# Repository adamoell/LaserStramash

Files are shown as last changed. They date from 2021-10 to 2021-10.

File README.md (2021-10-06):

# LaserStramash
Weapons-grade Free Software laser tag system.

Laser Stramash is a free/open Laser Tag system. It is designed with the following values in mind:
* Free: The software and hardware designs are all free to copy, use, modify and reuse. 
* Low cost: The system is designed to be inexpensive to implement and operate.
* Exciting: Laser Stramash should be fun to play, intense and varied.
* Accessible: Laser Stramash should be implementable by hobbyists with moderate software, 3D printing and electronics skills.
* Extensible: The system is designed to be easy to extend, including:
    * New game styles (can be implemented purely in software)
    * New mechanics (powerups etc)
    * New styles of gun etc that are drop-in compatible

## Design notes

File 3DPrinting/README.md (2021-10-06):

# LaserStramash 3D Printing
OpenSCAD designs for 3D printable guns.

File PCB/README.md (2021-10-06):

# LS Prototype PCB

This is an export from EasyEDA.

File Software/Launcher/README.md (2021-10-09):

# LaserStramash Launcher
Weapons-grade Free Software laser tag system.

The launcher is gathers up the necessary information to start a game, and then 
emits the MQTT messages necessary to get the game started.

In the prototype, it is the simplest of interactive command-line applications.
Eventually, this will be replaced with something neater - a PyQT app, or
a web interface or something.

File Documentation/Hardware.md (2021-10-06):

# Hardware

## Gun

## Sensor

## Other

Powerups, bases, waypoints?

## Infrastructure

Game server platform, FX platform

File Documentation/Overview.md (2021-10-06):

# Overview

TODO: Networked(MQTT), Python/MicroPython, 3D printed, ESP32

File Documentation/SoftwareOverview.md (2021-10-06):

# Software

## Game Server

TODO

## Launcher

TODO: Config & start game

## Monitor

TODO: Monitor game/player status

## FX Server

TODO

## Gun

TODO: 

Game class represents the Game. Subclass to create new games. NB this is
the ONLY class allowed to interact with the network client.

Player class represents a player.

Gun represents a gun (and 'has a' player)

Sensor represents a gun (and 'has a' player)

StramashClient handles networking protocol stuff

## Sensor

TODO

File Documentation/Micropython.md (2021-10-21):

# Setting Up the ESP32

## Flash Micropython

    sudo esptool.py --port /dev/ttyUSB0 erase_flash
    sudo esptool.py --chip esp32 --port /dev/ttyUSB1 write_flash -z 0x1000 Firmware/esp32-20210902-v1.17.bin

 or sudo screen /dev/ttyUSB0
 sudo picocom -b 115200 /dev/ttyUSB0
 and then if you need to:
    CTRL+d	preforms soft reboot
    CTRL+a x	exits picocom
    CTRL+a \	exits screen

## RShell

    rshell --buffer-size=30 -p /dev/ttyUSB0 -a

Sync with the device filesystem:

    rsync ./src /pyboard

Go into repl:

    repl 

ctrl-x to exit

and then "import foo" to run foo.py

## Check Memory

import micropython
micropython.mem_info()

## Check Flash

In repl:

    uos.statvfs("/")

Returns a tuple with the filesystem information in the following order:

    f_bsize – file system block size
    f_frsize – fragment size
    f_blocks – size of fs in f_frsize units
    f_bfree – number of free blocks
    f_bavail – number of free blocks for unprivileged users
    f_files – number of inodes
    f_ffree – number of free inodes
    f_favail – number of free inodes for unprivileged users
    f_flag – mount flags
    f_namemax – maximum filename length

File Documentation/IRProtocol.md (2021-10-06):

# Infrared Protocol

Laser Stramash uses the standard NEC infrared remote protocol. This
protocol operates on a 38kHz carrier frequency, and is implemented at
near-infrared wavelengths around 940nm. Using this protocol allows for
very inexpensive IR peripherals, large team sizes, and detailed tracking
of who hit whom, and where.

Each time the gun fires, it transmits an NEC data packet, much as a TV
remote would. An NEC packet consists of a 16-bit *address* and a 16-bit
*command*. Laser Stramash uses the error-corrected NEC-8 version, where
each packet consists of an 8-bit address and its complement, and and
8-bit command and its complement. This allows for solid error detection.
Laser Stramash encodes the firing player's *team* in the address field,
and their *id* in the command field. This allows for up to 256 teams,
each with up to 256 players.

The prototype uses Peter Hinch's micropython_ir library for sending and
decoding NEC data.

## References

micropython_ir:

<https://github.com/peterhinch/micropython_ir>

NEC protocol details:

<https://www.sbprojects.net/knowledge/ir/nec.php>

**Caution**

The NEC protocol is very commonly used in infrared remotes. It may be as
well to cover the receivers of any IR-controlled equipment in or near
your play space!

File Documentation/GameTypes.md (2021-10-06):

# Game Types

This section describes the game types available in the prototype.

Due to a limitation of the prototype hardware, IR hit recognition does
not work well while the network interface is active. The following
prototype games have been designed to work with the constraint that the
network connection will be *switched off* at game start, and switched on
again only when the game time is completed.

## Free-For-All

ID: ffa

Each player is their own 'team'. Players accumulate hits and kills until
the end of the game, when the guns all send their data to the server.

Game setup:

-   Time limit
-   SFX Server
-   Ammo clip size (max ammo) default=10
-   Reload Time default=5
-   Players

Game rules:
-   At game start, player has ammo=MAX
-   Usual state: gun is active, RGB solid light blue
-   On fire:
    -   If ammo:
        -   strobe RGB yellow
        -   decrease ammo
    -   else:
        -   strobe RGB pink
-   On reload:
    -   Player is inactive (can't fire) for n seconds
    -   RGB from black to full brightness solid light blue, then flash
        quickly to indicate complete
    -   Player reactivated, ammo set to MAX

-   When a player is killed:
    -   he is 'down' -- gun inactive for 10 sec
    -   RGB from black to white over 10 sec, then quick flash to
        indicate completed
    -   Player is reactivated and then shielded - 'bulletproof' - for 5
        sec (this is to stop someone 'standing over' a dead guy and
        rekilling)
    -   RGB solid red for this time, then back to light blue

At the end of the game, the guns all upload their hits and numbers of
shots fired. Score is computed as (kills -- deaths) + (kills /
shotsfired) -- that is, an integer 'net kills' with accuracy providing a
decimal 'tiebreaker'.

## Teams

ID: teams

Play is as per free-for-all above, except players are organised into
teams. 'Friendly fire' is ignored (ie doesn't count as a hit). Instead
of showing light blue in the default state, the RGB shows the team
colour.

Game setup:

-   Time limit
-   SFX Server
-   Ammo clip size (max ammo) default=10
-   Reload Time default=5
-   Teams
-   Players

## Stramash Royale

ID: royale

Play is as per free-for-all above, except that when a player is hit,
they are out -- gun disabled, RGB off, go sit on the bench until the
end. Last man standing is the winner; or if the time limit is reached,
the surviving players are ranked by score. Score is computed as (kills
-- deaths) + (kills / shotsfired) -- that is, an integer 'net kills'
with accuracy providing a decimal 'tiebreaker'.

Game setup:

-   Time limit
-   SFX Server
-   Ammo clip size (max ammo) default=10
-   Reload Time default=5
-   Players

Issue: the last man's gun won't know that he's the last man. May need to
manually trigger victory condition -- using a 'master blaster' game-over
transmitter?

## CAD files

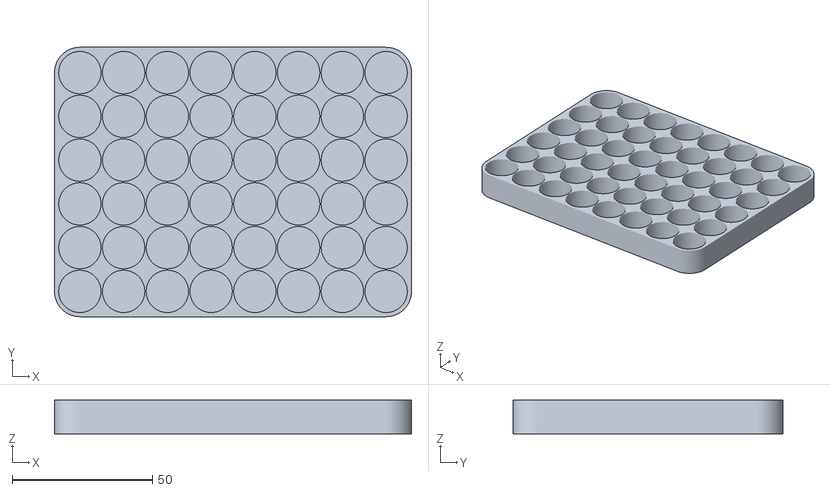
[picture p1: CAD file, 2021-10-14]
3DPrinting/STLs/AABatteryHolder_6x8.stl
127.3 x 96.1 x 12.0

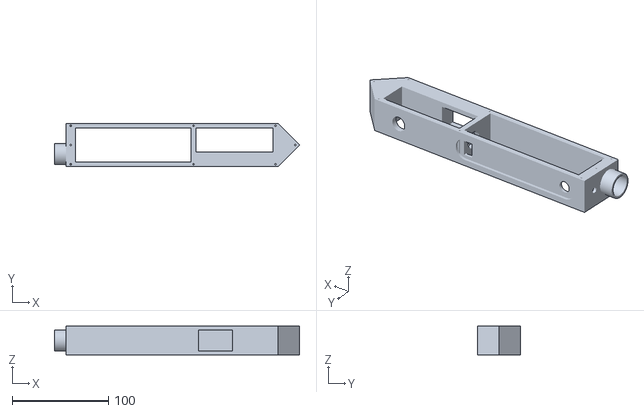
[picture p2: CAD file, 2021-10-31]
3DPrinting/STLs/PrototypeGun/Barrel.stl
254.5 x 45.0 x 30.0

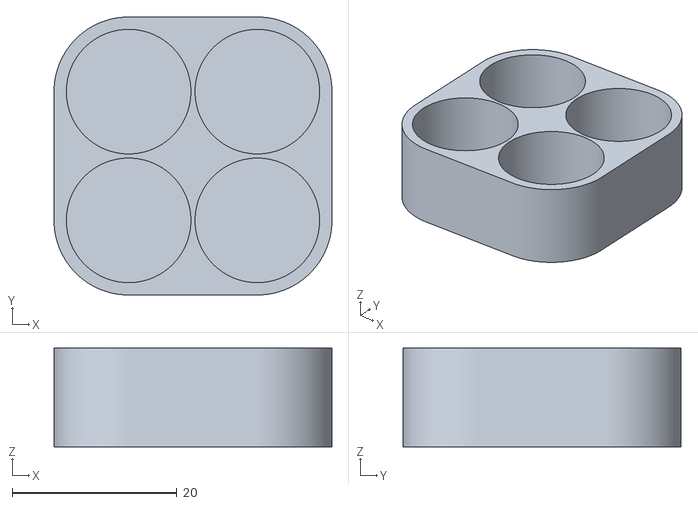
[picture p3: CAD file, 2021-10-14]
3DPrinting/STLs/AABatteryHolder.stl
33.7 x 33.7 x 12.0

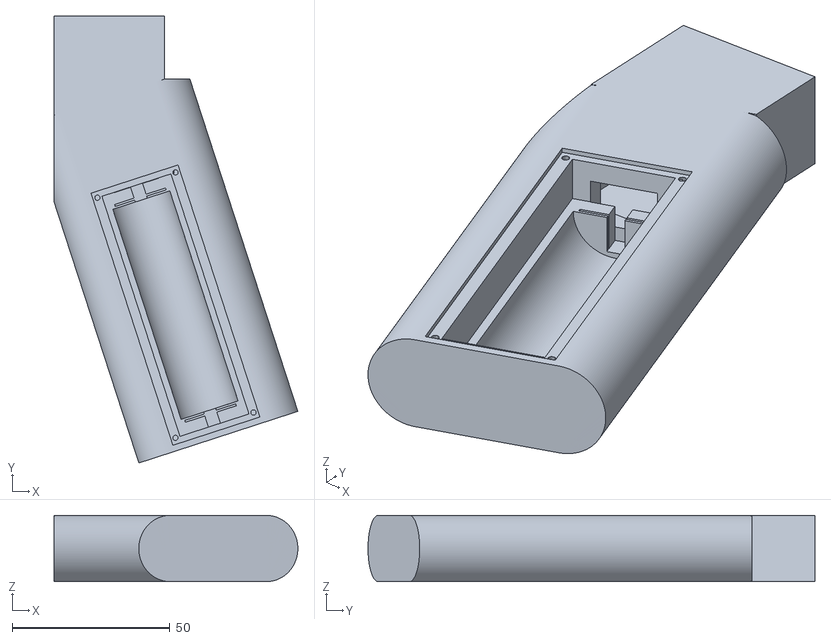
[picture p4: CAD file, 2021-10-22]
3DPrinting/STLs/PrototypeGun/Grip.stl
77.3 x 141.7 x 21.0

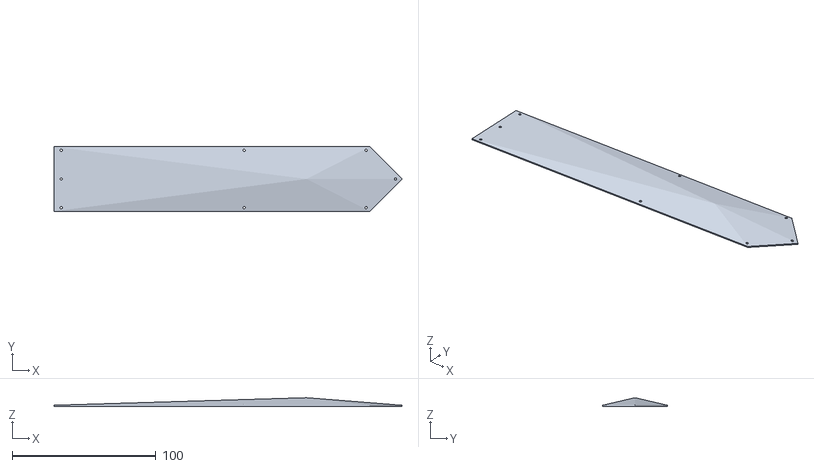
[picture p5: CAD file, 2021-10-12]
3DPrinting/STLs/PrototypeGun/SidePanel.stl
242.5 x 45.0 x 5.99

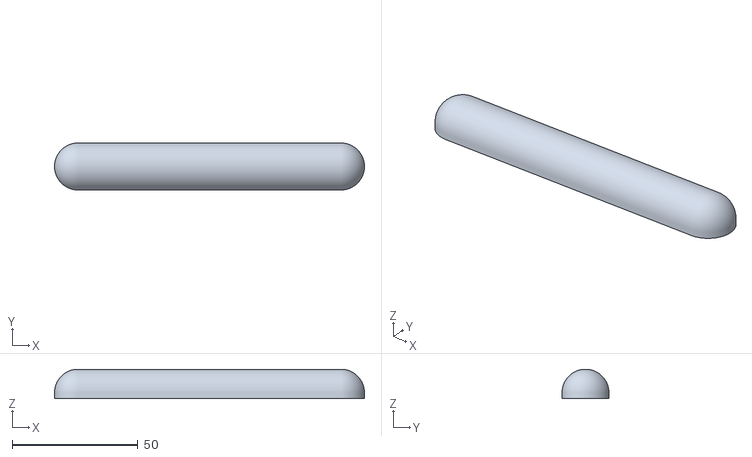
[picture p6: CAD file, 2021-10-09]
3DPrinting/STLs/PrototypeGun/RGBDiffuser.stl
123.4 x 18.7 x 11.7

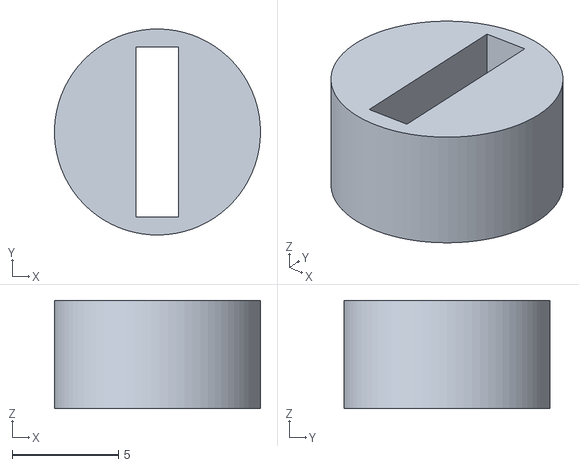
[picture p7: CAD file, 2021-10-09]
3DPrinting/STLs/PrototypeGun/IRRecvHolder.stl
9.70 x 9.70 x 5.10

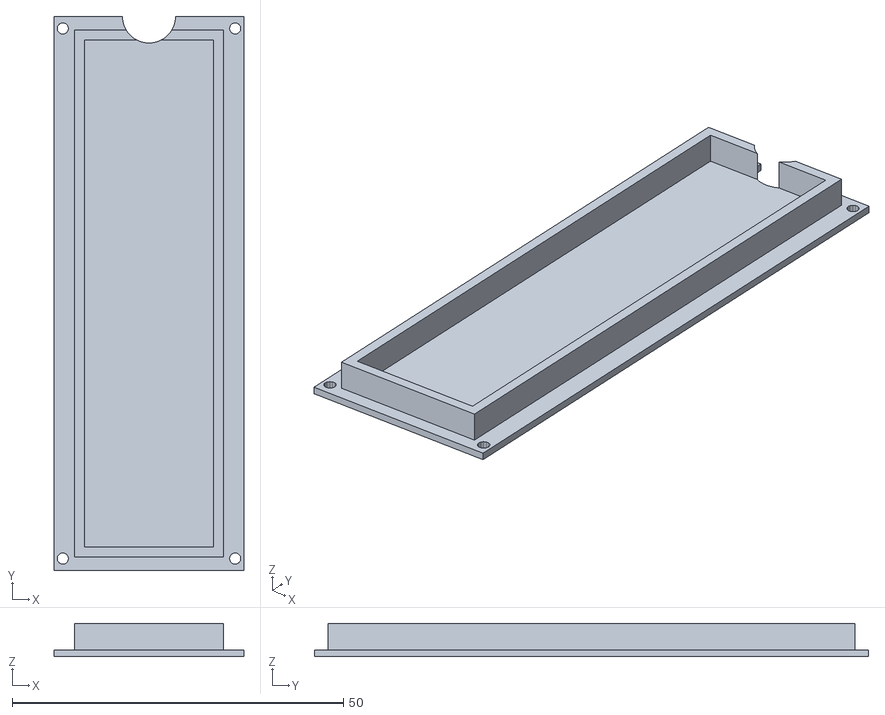
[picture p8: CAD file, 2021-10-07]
3DPrinting/STLs/PrototypeGun/BatteryCover.stl
28.6 x 83.6 x 5.00

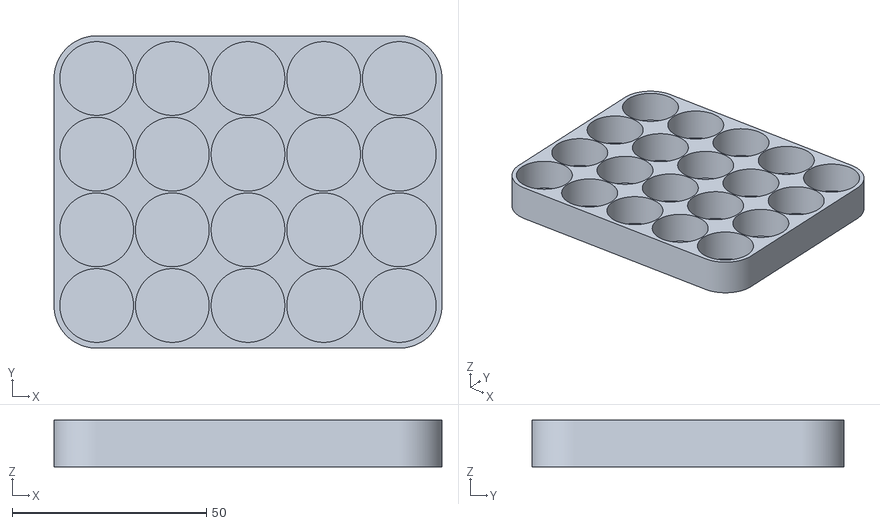
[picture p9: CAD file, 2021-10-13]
3DPrinting/STLs/18650BatteryHolder.stl
100.0 x 80.5 x 12.0

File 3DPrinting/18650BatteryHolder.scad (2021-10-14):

/*******************************************************************************
18650 Battery Holder
--
Copyright (C) 2021 Adam Oellermann
adam@oellermann.com
--
MIT License:
Permission is hereby granted, free of charge, to any person obtaining a copy of 
this software and associated documentation files (the "Software"), to deal in 
the Software without restriction, including without limitation the rights to 
use, copy, modify, merge, publish, distribute, sublicense, and/or sell copies of 
the Software, and to permit persons to whom the Software is furnished to do so, 
subject to the following conditions:

The above copyright notice and this permission notice shall be included in all 
copies or substantial portions of the Software.

THE SOFTWARE IS PROVIDED "AS IS", WITHOUT WARRANTY OF ANY KIND, EXPRESS OR 
IMPLIED, INCLUDING BUT NOT LIMITED TO THE WARRANTIES OF MERCHANTABILITY, 
FITNESS FOR A PARTICULAR PURPOSE AND NONINFRINGEMENT. IN NO EVENT SHALL THE 
AUTHORS OR COPYRIGHT HOLDERS BE LIABLE FOR ANY CLAIM, DAMAGES OR OTHER 
LIABILITY, WHETHER IN AN ACTION OF CONTRACT, TORT OR OTHERWISE, ARISING FROM, 
OUT OF OR IN CONNECTION WITH THE SOFTWARE OR THE USE OR OTHER DEALINGS IN THE 
SOFTWARE.
--
Release History
  0.1: 2021-10-06
    Initial release
*******************************************************************************/

$fa = 1;
$fs = 0.4;

/************************************************************************************
DIMENSIONS
*************************************************************************************/
battery_diameter = 14.5; // 18 for 18650, 14.5 for AA
battery_wiggle_room = 0.6; // added to diameter so batteries don't get stuck - 1 for 18650, .6 for AA
separator_thickness = 0.5; // thickness of the division between cells
base_thickness = 1.5; // thickness of the base
wall_thickness = 1.5; // thickness of the outer wall
height = 12; // total height
rows = 6; // number of rows
cols = 8; // number of columns

module located_cylinder(diam, height, x, y, z) {
  // just places a cylinder in a location
  translate([x,y,z])
    cylinder(d=diam, h=height);
}

module solid() {
  // the solid piece - each cell will be cut out of this
  
  x1 = 0;
  x2 = (cols-1) * (battery_diameter + battery_wiggle_room + separator_thickness);
  y1 = 0;
  y2 = (rows-1) * (battery_diameter + battery_wiggle_room + separator_thickness);
  
  diam = battery_diameter + battery_wiggle_room + (wall_thickness*2);
  
  hull() {
    located_cylinder(diam, height, x1,y1,0);
    located_cylinder(diam, height, x2,y1,0);
    located_cylinder(diam, height, x1,y2,0);
    located_cylinder(diam, height, x2,y2,0);
  }
}

module holes() {
  hole_diam = battery_diameter + battery_wiggle_room;
  for (i=[0:rows-1]) {
    for (j=[0:cols-1]) {
      hole_x = j * (hole_diam + separator_thickness);
      hole_y = i * (hole_diam + separator_thickness);;
      located_cylinder(hole_diam, height, hole_x,hole_y,base_thickness);
    }
  }
  
}
module holder() {
  // removes the cell holders
  difference() {
    solid();
    holes();
  }
}

holder();

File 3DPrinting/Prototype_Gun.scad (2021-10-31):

/*
Copyright (C) 2021 Adam Oellermann
adam@oellermann.com
--
  This file is part of Laser Stramash. 
  
  Laser Stramash is free software: you can redistribute it and/or modify
  it under the terms of the GNU General Public License as published by
  the Free Software Foundation, either version 3 of the License, or
  (at your option) any later version.

  Laser Stramash is distributed in the hope that it will be useful,
  but WITHOUT ANY WARRANTY; without even the implied warranty of
  MERCHANTABILITY or FITNESS FOR A PARTICULAR PURPOSE.  See the
  GNU General Public License for more details.

  You should have received a copy of the GNU General Public License
  along with this program.  If not, see <https://www.gnu.org/licenses/>
--
This file contains the design for the prototype Laser Stramash gun. A 
gun comprises a number of components, each generated by a module:
- The barrel - main body of the gun - module barrel()
- The lens holder - fits over end of barrel to hold 22mm lens
  module lens_holder()
- The side panel - two needed, one either side of the barrel - 
  module sidepanel()
- The infrared receiver holder - slots into the top of the barrel
  module ir_recv_holder()
- The grip - slots into the barrel, and has a void for an 18650 cell -
  module grip()
- The battery cover panel - covers the battery slot in the grip -
  module batt_panel_cover()
- The RGB diffuser - print in clear/natural PLA to diffuse RGB LEDs
  module rgb_diffuser()

These modules are invoked at the end of the file - just uncomment the one you want.
--
Release History
  0.1: 2021-10-03
    First draft of gun barrel and side panels.
  0.2: 2021-10-04
    Corrected hole size for IR LED, increased side panel thickness, first draft of grip
  0.3: 2021-10-06
    Redid the grip - better parameterisation, longer grip, shallower angle
    Cutout grip for battery, battery mount details
    half-moon cutout on batt_cover_panel to make it easier to remove
  0.4: 2021-10-07
    move grip hole forward
    move reload btn to top of utility void
    clearance for laser over lens assembly
    IR receiver assembly
    fixing details for diffuser
    diffuser
*/

$fa = 1;
$fs = 0.4;

/************************************************************************************
DIMENSIONS
*************************************************************************************/
// main barrel
barrel_length = 220;
barrel_height = 45;
barrel_thickness = 30;
barrel_skin = 4;
front_skin = 10;
pcb_void_height = 35;
pcb_void_length = 120;
barrel_skin_thickness = (barrel_height - pcb_void_height) / 2;

utility_void_length = 80;
utility_void_height = 25;
utility_void_separator = 5;

utility_hole_diameter = 15;

button_hole_diameter = 13; // reload button

side_panel_thickness_min = 0.75;
side_panel_thickness_max = 6;

// lens holder
lens_diameter = 22;
lens_holder_thickness = 2;
lens_holder_clearance = 0.3;
lens_holder_length = 10;
lens_holder_lip = 1;
flash_suppressor_length = 20;

// RGB diffuser 
rgb_internal_width = 15; // thin: 17 thick:15
rgb_wall = 2; // thin:1 thick:2
rgb_external_width = rgb_internal_width + rgb_wall * 2;
rgb_recess_depth = 2.4;
rgb_internal_length = 100; // thin:102 thick:100
ir_receiver_length = 20; // additional length to allow for IR receiver
rgb_external_length = rgb_internal_length + rgb_wall * 2 + ir_receiver_length;
rgb_diffuser_clearance = 0.3; // increased from 0.2
ir_recv_width = 6.8; // 6.8 for VS1838B, 6.1 for TSOP4438 
ir_recv_height = 8.0; // excl legs 8.0 for VS1838B, 6.8 for TSO4438
ir_recv_depth = 3.5; // excl bump 3.5 for VS1838B, 4.0 for TSOP4438
ir_recv_bumpdepth = 1.7; // 1.7 for VS1838B, 1.6 for TSOP4438  
ir_recv_bumpwidth = 4.2; // 4.2 for VS1838B, 4.2 for TSOP 4438 
ir_recv_rgb_clearance = 0.2;

// grip
grip_thickness=21;
grip_joint_length=35;
grip_joint_height=20;
grip_joint_xwall=8; // thickness of front (pierced by btn) and back wall
grip_joint_void_length = grip_joint_length-grip_joint_xwall;
grip_joint_void_thickness = 18;
grip_back_offset=20;
grip_socket_clearance = 0.4;
grip_angle = 18; // grip angle in degrees
grip_width = 32; // was 36.5
grip_height = 120;
grip_base_thickness = 4;
battery_diameter = 18; // 18650
battery_length = 65; // 18650
battery_clearance_x = 1; // wiggle room
battery_void_width = battery_diameter + 5; // wiggle room
battery_void_length = 80;
butt_length = adj_given_hyp(h=grip_height,angle=grip_angle); // length of the angled portion
batt_cover_thickness=1;
batt_cover_xlip = 3; // width of the 'lip' for the battery cover
batt_cover_ylip = 2; // height of the 'lip' for the battery cover
batt_wiring_width = 15; //wiring channel through into barrel
batt_wiring_thickness = 10;
batt_clearance = 0.4;
batt_panel_width = battery_void_width + (2*batt_cover_xlip) - batt_clearance;
batt_panel_height = battery_void_length + (2*batt_cover_ylip) - batt_clearance;
batt_socket_length = 70;
batt_spring_channel_width = 4;
batt_spring_width = 17; // official dim 16.5
batt_spring_height = 16.5; // official dim 16
batt_spring_thickness = 0.65; // was 0.5
batt_spring_retainer = 0.65; // was 0.5
batt_spring_plate_thickness = .2+(battery_void_length - batt_clearance - batt_socket_length)/2;
batt_cover_panel_clearance = 0.2;
batt_cover_panel_shrink = 0.2; // take this off from every edge
bc_width = battery_void_width + (2 * batt_cover_xlip) - (batt_cover_panel_shrink * 2);
bc_height = battery_void_length + (2 * batt_cover_ylip) - (batt_cover_panel_shrink * 2);

fire_plate = grip_joint_xwall;
fire_hole_diameter = 13;
fire_void_length = 30;
fire_void_width = 18;
fire_button_zoffset = 12;

// optics
optic_diameter = lens_diameter; // exactly matches lens diameter
optic_length = 22.0; // was 19.4, measure at 22.4
lensholder_diameter = 2;
optic_thickness = 2;
led_diameter = 5;
led_clearance = 0.5; // was 0.3
laserbeam_diam = 4.8; // was 5.0
laserbody_diam = 6.2; // measures 6, was 6.8, then 6.6, then 6.4 (still too loose) 
laser_lipdepth = 1;

ir_recv_socket_diam = 10;

/************************************************************************************
BARREL
*************************************************************************************/
module laser_hole() {
  // Holder for a 6mm laser dot - intended for friction fit plus glue
  // beam hole
  x_offset = 5;
  translate([-0.05,optic_diameter/2+optic_thickness+0.6+x_offset,0])
    optic_hole(laserbeam_diam, front_skin+0.1);
  // body hole
  translate([0.05,optic_diameter/2+optic_thickness+0.6+x_offset,0])
    optic_hole(laserbody_diam, front_skin-laser_lipdepth);
  
}

module optic_hole(diameter, length) {
  // hollow out the optic assembly
  translate([10,optic_diameter/2+lensholder_diameter,barrel_thickness/2])
  rotate([0,-90,0])
    cylinder(d=diameter, h=length);
}
module optic() {
  // cylindrical projection which holds the lens at the right focal distance
  // from the IR LED
  translate([10,optic_diameter/2+lensholder_diameter,barrel_thickness/2])
  rotate([0,-90,0])
    cylinder(d=optic_diameter, h=optic_length);
  
}

module pcb_void() {
  // Void for the PCB
  translate([front_skin,(barrel_height-pcb_void_height)/2,-0.05])
    cube([pcb_void_length, pcb_void_height, barrel_thickness+0.1]);
}
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

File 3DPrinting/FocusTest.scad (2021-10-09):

$fa = 1;
$fs = 0.4;

lens_diameter = 22;
led_diameter = 5;
led_clearance = 0.5; // was 0.3
led_carrier_thickness = 2;
led_carrier_clearance = 0.5;
led_carrier_plate = 2; // was 1, thickened to get the LED straighter
led_carrier_length = 150;

barrel_length = 150;
focussed_barrel_length = 22.0; // was 19.4, measure at 22.4
barrel_thickness = 2;

lens_holder_thickness = 2;
lens_holder_clearance = 0.3;
lens_holder_length = 10;
lens_holder_lip = 1;
flash_suppressor_length = 20;

// lens is held against end of barrel by lens holder
// led_carrier slides inside barrel to adjust focus

module barrel() {
  difference() {
    cylinder(d=lens_diameter, h=barrel_length);
    translate([0,0,-0.01])
    cylinder(d=lens_diameter-(2*barrel_thickness), h=barrel_length+0.02);
  }
}

module focussed_barrel() {
  rotate([0,180,0]) {
    difference() {
      cylinder(d=lens_diameter, h=focussed_barrel_length);
      translate([0,0,-0.01])
      cylinder(d=lens_diameter-(2*barrel_thickness), h=barrel_length+0.02);
    }
    
    // led mount
    led_carrier_od = lens_diameter-0.01;
    led_carrier_id = led_carrier_od - (2*led_carrier_thickness);
    translate([0,0,focussed_barrel_length-led_carrier_plate])
      difference() {
        cylinder(d=led_carrier_od, h=led_carrier_plate);
        translate([0,0,-0.01])
        cylinder(d=led_diameter + led_clearance, h=led_carrier_plate+0.02);
      }
  }
}

module lens_holder() {
  lens_holder_diameter = lens_diameter + (lens_holder_thickness * 2) + lens_holder_clearance;
 
  // sleeve
  difference() {
    cylinder(d=lens_holder_diameter, h=lens_holder_length);
    translate([0,0,-0.01])
    cylinder(d=lens_diameter + lens_holder_clearance, h=lens_holder_length+0.02);
  }
  
  // lip
  difference() {
    cylinder(d=lens_holder_diameter, h=lens_holder_thickness);
    translate([0,0,-0.01])
    cylinder(d=lens_diameter - (lens_holder_lip*2), h=lens_holder_length+0.02);
  }
  
  // flash suppressor
  flash_suppressor_id = lens_diameter + lens_holder_clearance;
  translate([0,0,-flash_suppressor_length + 0.01])
  difference() {
    cylinder(d=lens_holder_diameter, h=flash_suppressor_length);
    translate([0,0,-0.01])
      cylinder(d1=flash_suppressor_id, d2=(flash_suppressor_id-lens_holder_lip*2), h=flash_suppressor_length+0.02);
  }
}

module led_carrier() {
  led_carrier_od = lens_diameter-(2*barrel_thickness)-led_carrier_clearance;
  led_carrier_id = led_carrier_od - (2*led_carrier_thickness);
  // tube
  difference() {
    cylinder(d=led_carrier_od, h=led_carrier_length);
    translate([0,0,-0.01])
      cylinder(d=led_carrier_id, h=barrel_length+0.02);
    // cut out half the barrel to make it easier to run the wire
    translate([0,-led_carrier_od/2,led_carrier_plate+(led_carrier_thickness*4)])
      cube([led_carrier_od, led_carrier_od, led_carrier_length]);
  }
  
  // led mount
  difference() {
    cylinder(d=led_carrier_od, h=led_carrier_plate);
    translate([0,0,-0.01])
    cylinder(d=led_diameter + led_clearance, h=led_carrier_plate+0.02);
  }
}

//barrel();
//lens_holder();
//led_carrier();
focussed_barrel();

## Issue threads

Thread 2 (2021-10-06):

Correctly format tables in IRProtocol.md

adamoell, 2021-10-06:
<!-- Edit the body of your new issue then click the ✓ "Create Issue" button in the top right of the editor. The first line will be the issue title. Assignees and Labels follow after a blank line. Leave an empty line before beginning the body of the issue. -->

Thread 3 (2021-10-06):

Breakup legacy TODO.txt into documentation files

adamoell, 2021-10-06:
<!-- Edit the body of your new issue then click the ✓ "Create Issue" button in the top right of the editor. The first line will be the issue title. Assignees and Labels follow after a blank line. Leave an empty line before beginning the body of the issue. -->

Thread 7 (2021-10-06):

Create issues from all TODOs that will complete all the milestones.

adamoell, 2021-10-06:
<!-- Edit the body of your new issue then click the ✓ "Create Issue" button in the top right of the editor. The first line will be the issue title. Assignees and Labels follow after a blank line. Leave an empty line before beginning the body of the issue. -->

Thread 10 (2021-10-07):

Finalise Barrel

adamoell, 2021-10-07:
move grip hole forward
move reload btn to top of utility void (currently in the way of the PCB)
clearance for laser over lens assembly (currently obscured by lensholder)
IR receiver assembly
fixing details for diffuser on barrel
diffuser implementation

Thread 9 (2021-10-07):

Add lensholder into Prototype_Gun.scad

adamoell, 2021-10-07:
https://github.com/adamoell/LaserStramash/blob/94856b74902d175c93b1d0d810132ef434fd0608/3DPrinting/Prototype_Gun.scad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

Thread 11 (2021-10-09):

Corrections to diffuser

adamoell, 2021-10-09:
Friction fit needs to be ever so slightly looser (0.1 would do). Lengthen diffuser a little and move forward (together with cable slot) to get IR receiver under the dome. This may require making the diffuser slightly taller?

Maybe do internal 'bubbles' to diffuse better lengthwise? Or print in natural PLA?

adamoell, 2021-10-09:
The IR receiver *JUST* fits without having to increase height. Decided to leave the internal 'bubbles' for now and try printing with Natural PLA.

Closed 2021-10-09.

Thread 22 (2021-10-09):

Write up prototype assessment

adamoell, 2021-10-09:
**Assess:**

-   LED/receiver range -- well lit, darkness
-   Accuracy required for hit
-   3D-printed diffuser effectiveness
-   Laser brightness for smoke gen
-   Simple play-testing
-   Protocol
-   Networking speed etc
-   What happens when we pull the network cables etc?
-   Do we need a separate chip to do IR decoding, eg ATtiny85
    <https://github.com/fotisl/ir2i2c>
    -   ATtiny85 getting started
        <https://electronut.in/getting-started-with-attiny85-avr-programming/>
    -   Reasonable price from rs-online
    -   Even better from microchip direct?
        <https://www.microchipdirect.com/product/ATTINY85-20PU?productLoaded=true>
    -   Or just use a D1 mini?
        https://github.com/peterhinch/micropython-mqtt

**Outline Beta Scope**
Beta to be scoped out after prototype evaluation

-   Additional gun peripherals

    -   screen
    -   sound
    -   vibration
    -   RFID -- for position-based respawn, powerups etc
    -   capacitive sensing to ensure hand on gun, not covering sensor
    -   reset pin (short GND to EN?)

-   PCB changes

    -   Break out other gpios, power pins etc 'just in case' --
        upgradeable!
    -   Reset button -- short EN to ground?
    -   KF2510-2A and 4a connectors
    -   Go with bare module? Break out programming?
    -   Mounting holes
    -   Separate IC (eg ATtiny85) for IR decode? Or use ESP8266 with
        Peter Hinch's MQTT bridge?
    -   Peripherals
    -   Power supply/charger on board? TP4056? Or use LiFePO4 and
        dispense with?
    -   SMT? and get it assembled?
    -   Polyfuse for battery?

-   3D model changes

-   Software changes

    -   OTA updates of Python code?

Additional games

Playtesting at Milestone

adamoell, 2021-10-09:
Alternative to ATtiny85 - just offload the IR to an ESP8266. Use C library code like this:
https://forum.arduino.cc/t/extreme-lightweight-ir-sender-for-nec-protocol/858910
receiver counterpart is here. Should be OK to use that board to do the sending AND receiving.

adamoell, 2021-10-09:
Great details about getting a bare ESP-12F module to boot/program in this video: https://www.youtube.com/watch?v=_iX67plFeLs

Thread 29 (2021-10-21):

Hole for laser dot is too loose

adamoell, 2021-10-21:
Reduce hole diameter by 0.2mm to ensure tight fit.

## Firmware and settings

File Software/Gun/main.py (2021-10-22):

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
import time
import machine
import gc
from stramashclient import *
from player import *
from sensor import Sensor
from gun import Gun
from utils import *
from fx import *

config = Config("ls.json")

# Announce the game version
ls_version = config.get('Game:version')   
header = "Laser Stramash "+ls_version
dbg(header)
dbg("-"*len(header))

# clock faster for IR
machine.freq(240000000) # default is 160000000
dbg('ESP32 running at ' + str(machine.freq()))

id = config.get('Hardware:identifier') # unique identifier for this hardware

# setup player
player = Player(id)

# setup FX
laser_pin = config.get_int('Hardware:laser_pin')
laser_brightness = config.get_int('Hardware:laser_brightness') # 0=off, 1023=max
laser = Laser(laser_pin, laser_brightness, player)

rgb_pin = config.get_int('Hardware:rgb_pin')
rgb_num_pixels = config.get_int('Hardware:rgb_num_pixels')
rgb = RGB(rgb_pin, rgb_num_pixels, player)

fx = FX()
fx.add(laser)
fx.add(rgb)
player.fx = fx

# bootup FX 
rgb.base_colour = RED
rgb.bootup()
time.sleep(1)
rgb.update()

# setup sensor
ir_recv_pin = config.get_int('Hardware:ir_recv_pin')
sensorid = config.get_int('Hardware:gun_sensor_id')
sensorname = config.get('Hardware:gun_sensor_name')
sensor = Sensor(ir_recv_pin, sensorid, sensorname, player, fx, True)

# setup gun
dbg('Initialising gun...')
fire_pin = config.get_int('Hardware:fire_pin')
reload_pin = config.get_int('Hardware:reload_pin')
ir_send_pin = config.get_int('Hardware:ir_send_pin')
max_ammo = 10 # should get overridden by game
reload_time = 5 # should get overridden by game
gun = Gun(fire_pin, reload_pin, ir_send_pin, fx, player, max_ammo, reload_time)

rgb.base_colour = ORANGE
rgb.update() 
dbg('Connecting to server...')
wifi_ssid = config.get('Network:wifi_ssid')
wifi_key = config.get('Network:wifi_key')
server_address = config.get('Network:mqtt_server_address')
stramash = StramashClient(id, server_address, wifi_ssid, wifi_key)
# TODO: hook ongamejoined callback from stramash client and use it to 
# 'save' the game and populate its gun, sensor, player

# indicate network connected
rgb.base_colour = GREEN
rgb.connected()
time.sleep(1)
rgb.update()

###############################################################################
# TEST CODE this stuff should really be done by a Game
###############################################################################
testteam = Team(2, 2, (128, 0, 0), "Test Team")
testgame = "Test Game" # TODO this should be a Game object!

#player.onstatechanged = rgb.handlestatechange # let the RGB update when player state changes
player.assign(testteam)
player.joingame(testgame)
player.up()
# TODO player.joingame --> gun, sensor
# Game hooks sensor.onhit - mark player and gun as dead
# ie game logic... probably reload, can_fire, can_reload handled here...
# TODO game needs to maintain a list of enemy teams VALIDATED by the Fire method
# when the game starts, turn off WiFi.

###############################################################################
# event loop
dbg('Starting Event Loop')
try:
    while True:
        stramash.update() # TODO can we schedule this with a thread in the StramashClient?
        time.sleep(1)
        gc.collect()
except KeyboardInterrupt:
    sensor.close()
    fx.close()

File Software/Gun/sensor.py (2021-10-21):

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
# though probably this will move onto separate hardware (eg ATtiny85) soon,
# as the code recognition is a bit unstable when the ESP32 is doing other 
# things. See:
# https://github.com/fotisl/ir2i2c
# Have a wee look at comment here: https://github.com/fotisl/ir2i2c/issues/1
# re. a more efficient version happy at 8mHz

import time
from machine import Pin, freq
from ir_rx.print_error import print_error  # Optional print of error codes
from ir_rx.nec import NEC_8, NEC_16
from game import Hit
from utils import inttohexstring, dbg



def neccode(addr, data):
    return inttohexstring(addr)+":"+inttohexstring(data)

class Sensor:
    def __init__(self, pin, sensorid, sensorname, player, fx, excludefriendly=True):
        """
        Setup the sensor. Raises callbacks: onhit, onfriendlyfire if these
        are assigned

        pin: the GPIO pin number of the IR sensor
        sensorid: the id of the sensor
        sensorname: the name of this sensor
        player: the player
        excludefriendly: if True, exclude friendly fire
        onhit: optional callback to invoke when a hit is verified
        """
        # initialise IR receiver
        ir_recv_pin = Pin(pin, Pin.IN)
        self.ir = NEC_8(ir_recv_pin, self.handle_ir)  # Instantiate receiver
        self.sensorid = sensorid
        self.sensorname = sensorname
        self.player = player
        self.excludefriendly = excludefriendly
        self.onhit = None
        self.onfriendlyfire = None
        self.hits = []
        self.fx = fx

    # handle received IR code
    def handle_ir(self, data, addr, ctrl): 
        if data > 0: # ignore repeat codes
                
            if self.player.canbehit: # can we be hit? IE not shielded, dead etc
                myteam = self.player.team.team
                myplayer = self.player.team.player

                hit = Hit(addr, data, myteam, myplayer, self.sensorid)
                friendlyfire = (addr == myteam)
                if (not friendlyfire) or (not self.excludefriendly): # no friendly fire!
                    self.hits.append(hit)
                    dbg("hit: counter=" + str(len(self.hits)))
                    self.fx.hit()
                    if self.onhit != None:
                        self.onhit(hit)
                else:
                    # Deal with friendly fire here if needed - but only if this wasn't me shooting myself!
                    if myplayer != data:
                        if self.onfriendlyfire != None:
                            self.onfriendlyfire(hit)
                        dbg("hit: not counting friendly fire")
            else:
                # deal with unhittable player if needed
                dbg("hit: not hittable, state="+str(self.player.state))
            
            
    def close(self):
        self.ir.close()

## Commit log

2021-10-06 Added the prototype PCB.
2021-10-06 Added 3D printable gun prototype.
    [Prototype_Gun.scad]
2021-10-07 Added cutout to battery cover
    [BatteryCover.stl]
2021-10-07 Updated battery cover for easier removal
    [Prototype_Gun.scad]
2021-10-07 Updated RGB to deal with a strip of LEDs
    [Prototype_Gun.scad]
2021-10-07 Completed diffuser and barrel changes
    [Prototype_Gun.scad]
2021-10-09 Updates to 3D design
    [Barrel.stl, IRRecvHolder.stl, RGBDiffuser.stl]
2021-10-09 Models used to calc proper focus distance for IR.
    [FocusTest.scad]
2021-10-09 Added lens holder part
    [Prototype_Gun.scad]
2021-10-09 Typo fixed
    [Prototype_Gun.scad]
2021-10-09 Corrected issue with firing callbacks.
    [fx.py, gun.py]
2021-10-09 Modified diffuser to incorporate IR receiver
    [Prototype_Gun.scad, RGBDiffuser.stl]
2021-10-10 Slightly tightened grip socket, fixed IR recv hole
    [Prototype_Gun.scad]
2021-10-11 Aligned IR recv hole in barrel with posn in diff
    [Barrel.stl, Prototype_Gun.scad]
2021-10-12 Generated side panel STL
    [Prototype_Gun.scad, SidePanel.stl]
2021-10-13 Reduced height for faster printing.
    [18650BatteryHolder.scad, 18650BatteryHolder.stl]
2021-10-14 Added AA battery holder.
    [18650BatteryHolder.scad, AABatteryHolder.stl]
2021-10-14 Added AA battery holder 6x8
    [18650BatteryHolder.scad, AABatteryHolder_6x8.stl]
2021-10-19 Updated sample config for gun
2021-10-21 Moved debug prints into utils.dbg()
2021-10-21 Moved debug prints to used utils.dbg()
2021-10-21 Moved debug prints to use utils.dbg()
2021-10-22 Adjusted grip to accomodate battery springs better
    [Grip.stl, Prototype_Gun.scad]
2021-10-31 Tighted up slop for laser module - better pointing
    [Barrel.stl, Prototype_Gun.scad]
